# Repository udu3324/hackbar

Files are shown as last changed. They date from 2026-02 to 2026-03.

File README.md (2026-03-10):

# hackbar

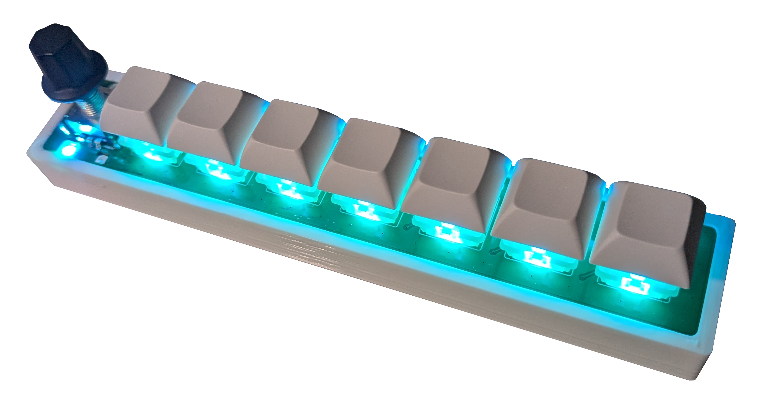
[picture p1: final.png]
hackbar photo


Hackbar is a macro keys pad in the shape of a bar designed to be placed on the long side of your keyboard. It features 7 switches, an encoder, and two neopixels per key and encoder. It is also inspired by the [Google g-board april fools video](https://www.youtube.com/watch?v=9G3DWHf1xX0). 

# firmware

KMK firmware is used to tell what the mcu sends to the host device when recieving switch inputs. 

# CAD

The cad can be found on [onshape](https://cad.onshape.com/documents/5cba3b888e11db533a85f54f/w/c697cc47e3473bff9588772d/e/0aef22490cba32d3fbb4fb29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). 

# Why I Made It

I wanted a macro keyboard that felt like the media control boards used in the a/v industry. They feature toggled leds that are vibrant and bright and look satisfying. I also would like to share this board with some of my friends as its very simple and easy to understand.

# How to Use 

The Seeed Xiao RP2040 makes flashing code very easy through circuitpython on the usb-c. 

# Photos

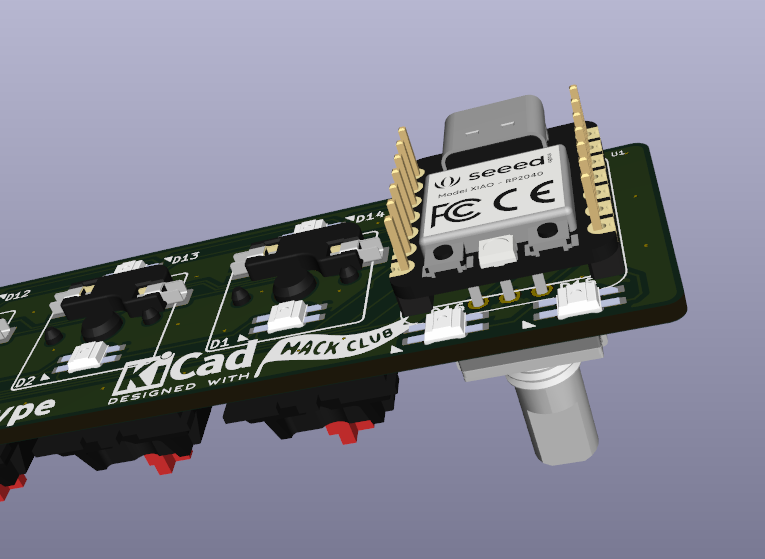
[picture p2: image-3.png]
render 2


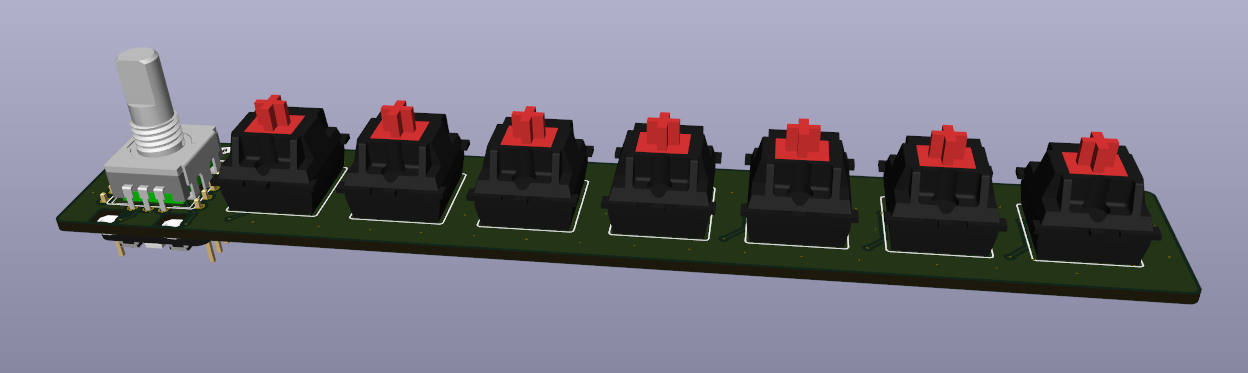
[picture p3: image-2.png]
render 1


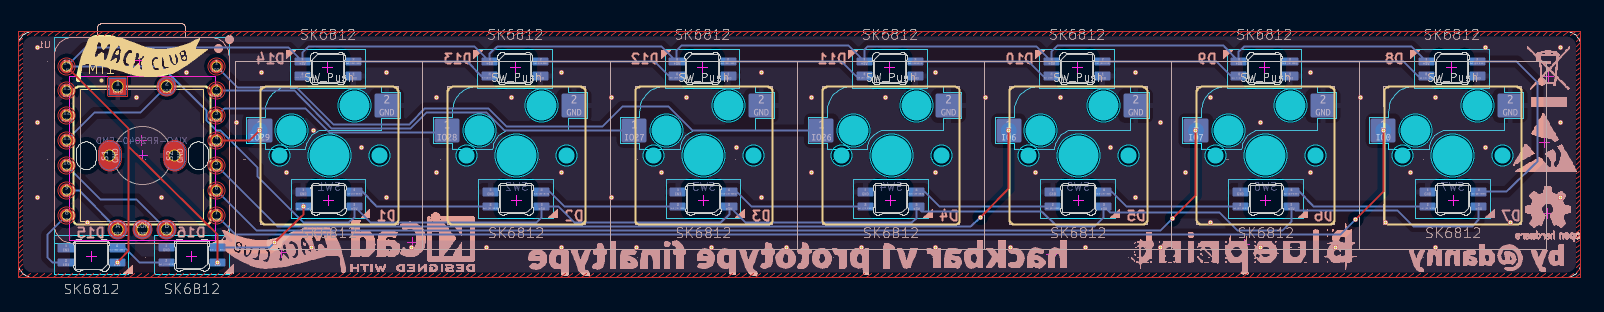
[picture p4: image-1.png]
pcb


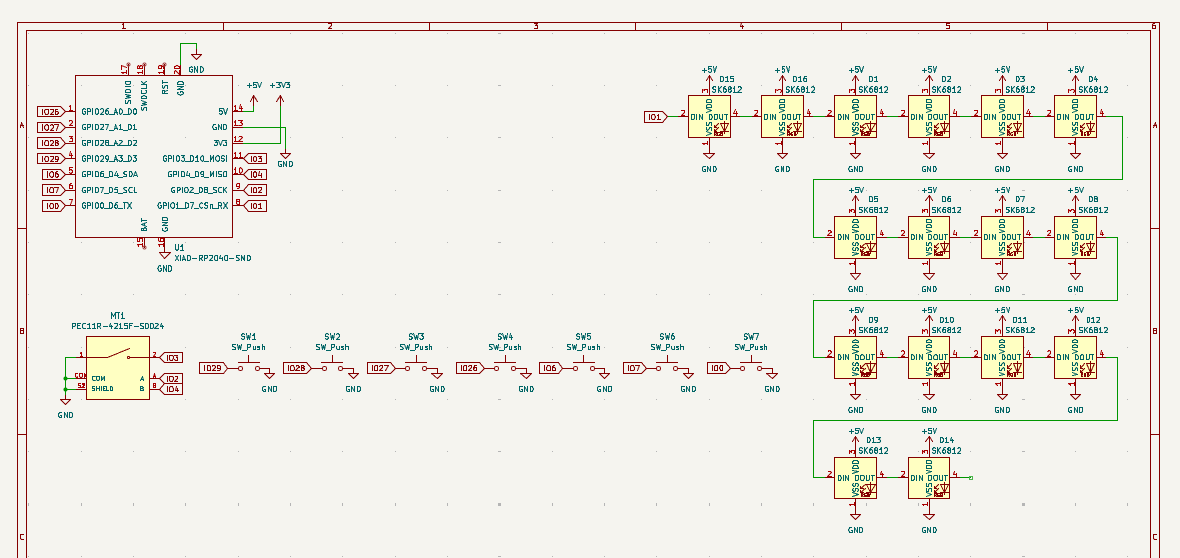
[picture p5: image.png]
schematics


# Bill of Materials

|Part |Quantity|On hand|Price |
|---|---|---|---|
|DSA Keycaps |7 |no | |
|Switches |7 |no | |
|Rotary Encoder Cap|1 |no | |
|Rotary Encoder |1 |no | |
|SK6812 MINI-E LEDs|16 |no | |
|PCB | |no |$9.55 |
|Seeed XIAO RP2040 |1 |no | |
|3d Printed Case |1 |yes | |
|Hot-swap Socket |7 |yes | |

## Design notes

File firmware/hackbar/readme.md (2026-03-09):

# hackbar

hackbar

*A short description of the keyboard/project*

* Keyboard Maintainer: [udu3324](https://github.com/udu3324)
* Hardware Supported: *The PCBs, controllers supported*
* Hardware Availability: *Links to where you can find this hardware*

Make example for this keyboard (after setting up your build environment):

    make hackbar:default

Flashing example for this keyboard:

    make hackbar:default:flash

See the [build environment setup](https://docs.qmk.fm/#/getting_started_build_tools) and the [make instructions](https://docs.qmk.fm/#/getting_started_make_guide) for more information. Brand new to QMK? Start with our [Complete Newbs Guide](https://docs.qmk.fm/#/newbs).

## Bootloader

Enter the bootloader in 3 ways:

* **Bootmagic reset**: Hold down the key at (0,0) in the matrix (usually the top left key or Escape) and plug in the keyboard
* **Physical reset button**: Briefly press the button on the back of the PCB - some may have pads you must short instead
* **Keycode in layout**: Press the key mapped to `QK_BOOT` if it is available

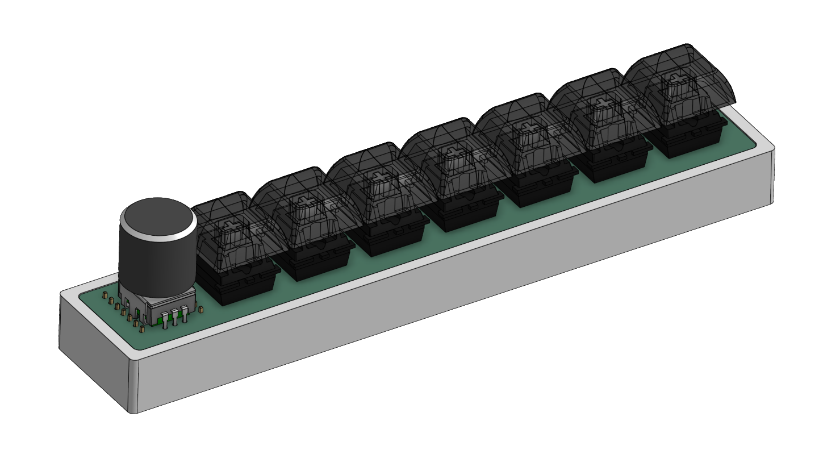
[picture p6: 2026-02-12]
img.png

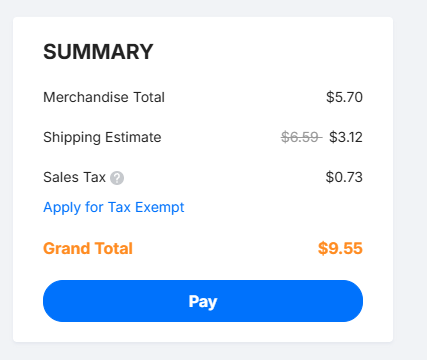
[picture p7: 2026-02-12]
cart.png

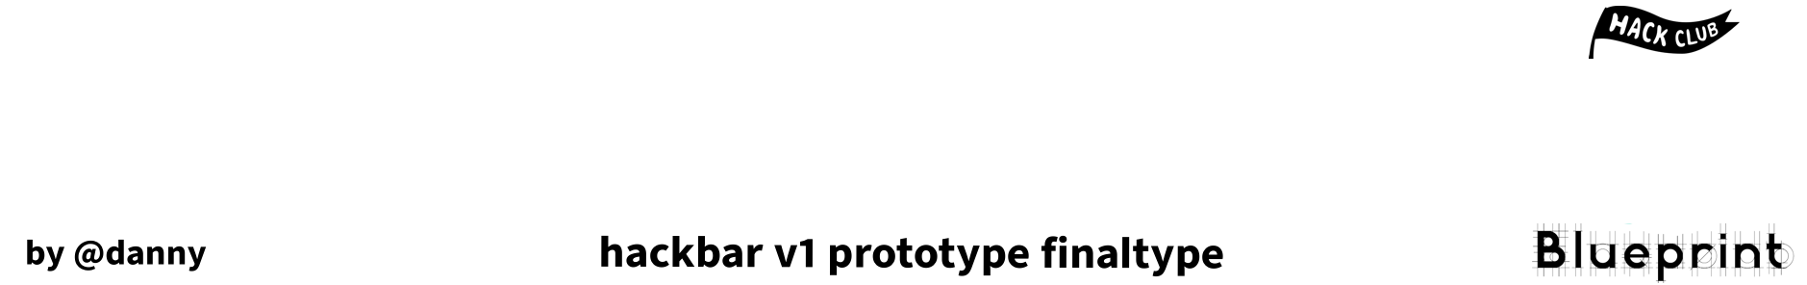
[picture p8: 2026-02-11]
pcb/hackbar-B_Silkscreen.png

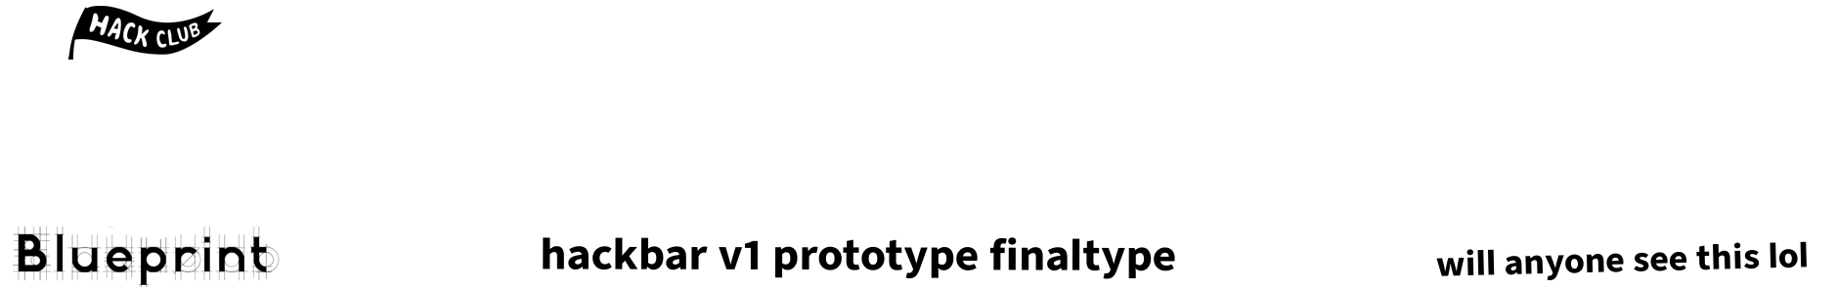
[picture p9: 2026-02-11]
pcb/hackbar-F_Silkscreen.png

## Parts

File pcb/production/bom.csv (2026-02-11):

Designator | Footprint | Quantity | Value | LCSC Part #
D1, D10, D11, D12, D13, D14, D2, D3, D4, D5, D6, D7, D8, D9 | SK6812MINI-E_fixed | 14 | SK6812
MT1 | PEC11R-4215F-S0024_XDCR_PEC11R-4215F-S0024 | 1 | PEC11R-4215F-S0024
SW1, SW2, SW3, SW4, SW5, SW6, SW7 | MX-Hotswap-1U | 7 | SW_Push
U1 | XIAO-RP2040-DIP | 1 | XIAO-RP2040-SMD

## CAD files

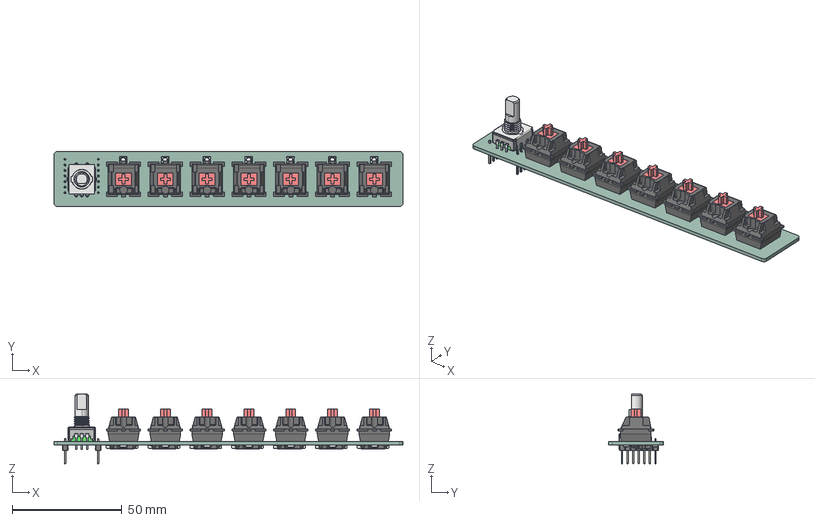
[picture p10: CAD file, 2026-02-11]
cad/hackbar pcb.step
159.0 x 25.0 x 31.7 mm
SK6812-E--3DModel-STEP-418109 x 14
PEC11R-4215F-S0024
MX-Hotswap-Socket x 7
PinHeader_1x07_P2.54mm_Vertical x 2
hackbar_PCB

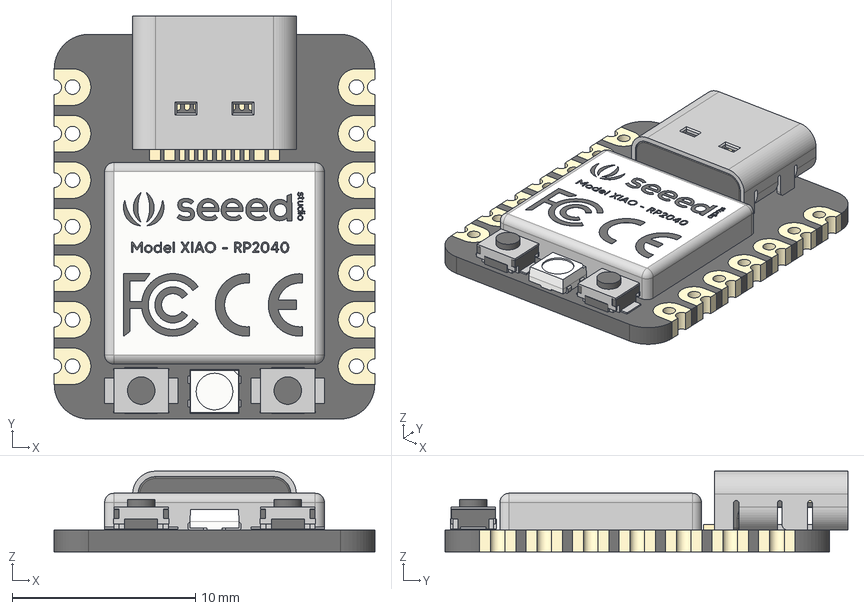
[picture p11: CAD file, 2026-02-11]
pcb/Seeed Studio XIAO RP2040 v26.step
17.5 x 22.0 x 4.40 mm
type-c v2
smd_button v3
DOUT
DIN
VSS
VDD
smd_button v3(Mirror)

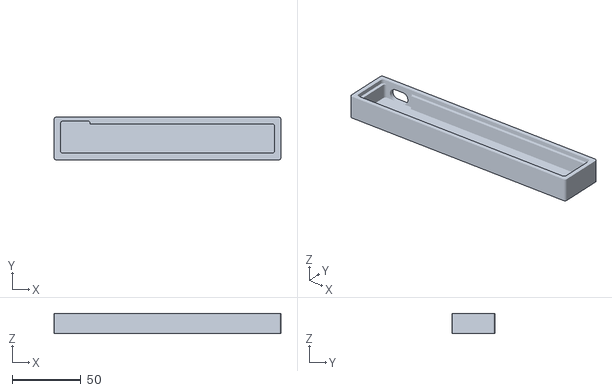
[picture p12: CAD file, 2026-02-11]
cad/hackbar case.stl
165.0 x 31.0 x 14.9

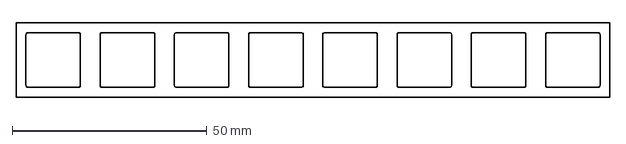
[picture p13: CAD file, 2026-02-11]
pcb/plate-2026-02-11T03_17_20.273Z.dxf
152.4 x 19.1 mm

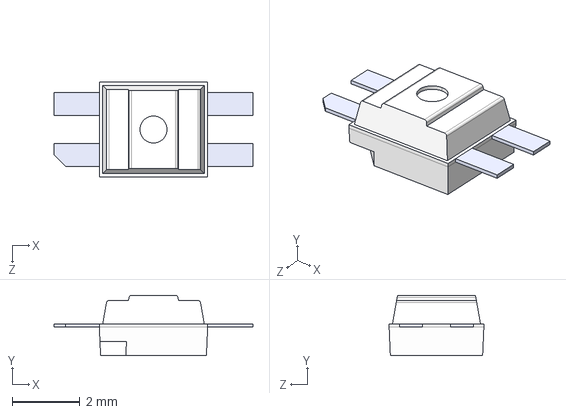
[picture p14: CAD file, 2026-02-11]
pcb/SK6812-E--3DModel-STEP-418109.STEP
5.88 x 1.78 x 2.80 mm

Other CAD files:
cad/hackbar case.x_t

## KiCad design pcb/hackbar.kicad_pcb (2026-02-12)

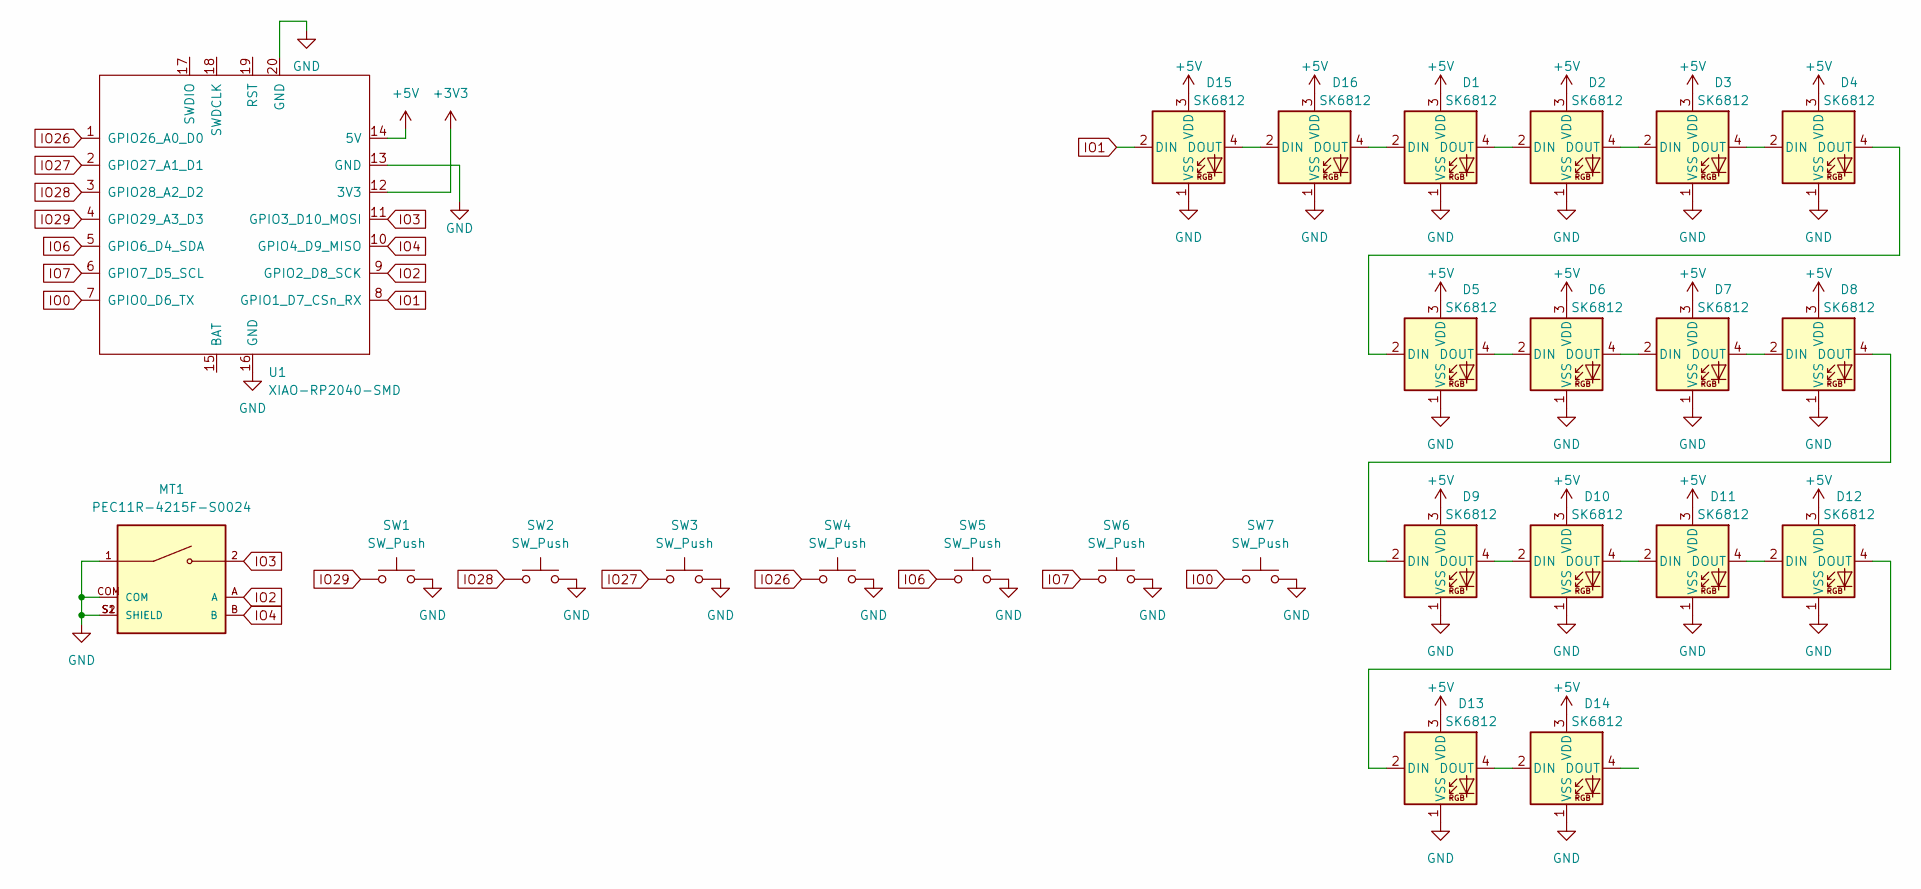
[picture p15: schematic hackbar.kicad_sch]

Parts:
D1, D2, D3, D4, D5, D6, D7, D8, D9, D10, D11, D12, D13, D14, D15, D16: SK6812; SK6812MINI-E_fixed
MT1: PEC11R-4215F-S0024; PEC11R-4215F-S0024_XDCR_PEC11R-4215F-S0024; PARTREV Rev. 09/19
SW1, SW2, SW3, SW4, SW5, SW6, SW7: SW_Push; MX-Hotswap-1U
U1: XIAO-RP2040-SMD; XIAO-RP2040-DIP

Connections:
+3V3: U1.12 (3V3)
+5V: D1.3 (VDD), D2.3 (VDD), D3.3 (VDD), D4.3 (VDD), D5.3 (VDD), D6.3 (VDD), D7.3 (VDD), D8.3 (VDD), D9.3 (VDD), D10.3 (VDD), D11.3 (VDD), D12.3 (VDD), D13.3 (VDD), D14.3 (VDD), D15.3 (VDD), D16.3 (VDD), U1.14 (5V)
GND: D1.1 (VSS), D2.1 (VSS), D3.1 (VSS), D4.1 (VSS), D5.1 (VSS), D6.1 (VSS), D7.1 (VSS), D8.1 (VSS), D9.1 (VSS), D10.1 (VSS), D11.1 (VSS), D12.1 (VSS), D13.1 (VSS), D14.1 (VSS), D15.1 (VSS), D16.1 (VSS), MT1.1, MT1.COM, MT1.S1 (SHIELD), MT1.S2 (SHIELD), SW1.2, SW2.2, SW3.2, SW4.2, SW5.2, SW6.2, SW7.2, U1.13 (GND), U1.16 (GND), U1.20 (GND)
IO0: SW7.1, U1.7 (GPIO0_D6_TX)
IO1: D15.2 (DIN), U1.8 (GPIO1_D7_CSn_RX)
IO2: MT1.A, U1.9 (GPIO2_D8_SCK)
IO3: MT1.2, U1.11 (GPIO3_D10_MOSI)
IO4: MT1.B, U1.10 (GPIO4_D9_MISO)
IO6: SW5.1, U1.5 (GPIO6_D4_SDA)
IO7: SW6.1, U1.6 (GPIO7_D5_SCL)
IO26: SW4.1, U1.1 (GPIO26_A0_D0)
IO27: SW3.1, U1.2 (GPIO27_A1_D1)
IO28: SW2.1, U1.3 (GPIO28_A2_D2)
IO29: SW1.1, U1.4 (GPIO29_A3_D3)
unnamed: D1.2 (DIN), D16.4 (DOUT)
unnamed: D1.4 (DOUT), D2.2 (DIN)
unnamed: D2.4 (DOUT), D3.2 (DIN)
unnamed: D3.4 (DOUT), D4.2 (DIN)
unnamed: D4.4 (DOUT), D5.2 (DIN)
unnamed: D5.4 (DOUT), D6.2 (DIN)
unnamed: D6.4 (DOUT), D7.2 (DIN)
unnamed: D7.4 (DOUT), D8.2 (DIN)
unnamed: D8.4 (DOUT), D9.2 (DIN)
unnamed: D9.4 (DOUT), D10.2 (DIN)
unnamed: D10.4 (DOUT), D11.2 (DIN)
unnamed: D11.4 (DOUT), D12.2 (DIN)
unnamed: D12.4 (DOUT), D13.2 (DIN)
unnamed: D13.4 (DOUT), D14.2 (DIN)
unnamed: D15.4 (DOUT), D16.2 (DIN)

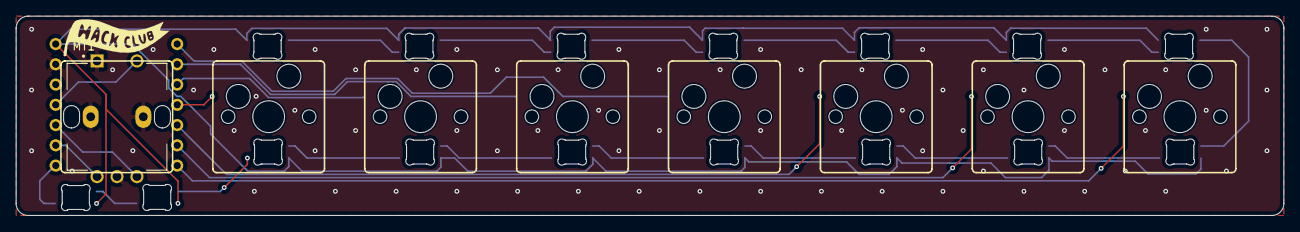
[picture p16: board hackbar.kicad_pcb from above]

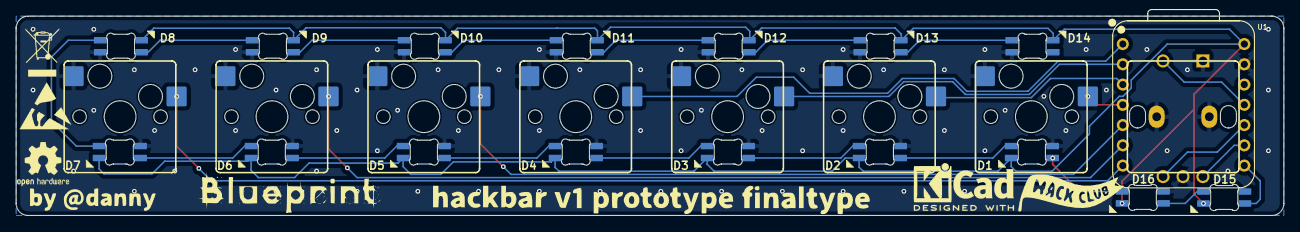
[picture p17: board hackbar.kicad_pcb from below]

Board: 2 copper layers, 159.0 x 25.0 mm, 25 parts (8 on the bottom side), 28 nets.

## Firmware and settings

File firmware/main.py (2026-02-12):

import board
from kmk.kmk_keyboard import KMKKeyboard
from kmk.keys import KC
from kmk.modules.encoder import EncoderHandler
from kmk.extensions.rgb import RGB
from kmk.modules.macros import Press, Release, Tap, Macros

# Initialize
keyboard = KMKKeyboard()

keyboard.diode_orientation = None

keyboard.modules.append(Macros())

# direct pin to switches, no matrix
keyboard.direct_pins = [
    board.D3,
    board.D2,
    board.D1,
    board.D0,
    board.D4,
    board.D5,
    board.D6
]

# Knob
encoder_handler = EncoderHandler()
encoder_handler.pins = (
    (board.D8, board.D9, board.D10, False),
)
# Knob click toggles between layers
encoder_handler.map = [
    ((KC.MEDIA_VOLUME_UP, KC.MEDIA_VOLUME_DOWN, KC.TG(1)),),
    ((KC.MEDIA_VOLUME_UP, KC.MEDIA_VOLUME_DOWN, KC.TG(1)),),
]

keyboard.modules.append(encoder_handler)

# LEDs
rgb = RGB(
    pixel_pin=board.D7,
    num_pixels=16,
    rgb_order='GRB',
    animation_mode=RGB.RAINBOW
)
keyboard.extensions.append(rgb)

# ex. of macro: KC.MACRO(Press(KC.LCTRL), Tap(KC.C), Release(KC.LCTRL))

# Keymap
keyboard.keymap = [
    # Layer 0:
    [
        KC.Q, 
        KC.W, 
        KC.E, 
        KC.R, 
        KC.T, 
        KC.Y, 
        KC.U
    ],
    
    # Layer 1:
    [
        KC.PSCREEN, # screenshot
        KC.MACRO(Press(KC.LALT), Tap(KC.F9), Release(KC.LALT)), # record toggle
        KC.MACRO(Press(KC.LALT), Press(KC.LSHIFT), Tap(KC.F10), Release(KC.LSHIFT), Release(KC.LALT)), # instant replay
        KC.Q, 
        KC.W, 
        KC.E, 
        KC.LWIN(KC.L) # lock screen
    ],
]

if __name__ == '__main__':
    keyboard.go()

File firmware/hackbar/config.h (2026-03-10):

// Copyright 2023 QMK
// SPDX-License-Identifier: GPL-2.0-or-later

#pragma once

#define RGBLIGHT_LIMIT_VAL 60
#define RGBLIGHT_SLEEP
#define RGBLIGHT_LAYERS

#define ENCODER_RESOLUTION 4
#define ENCODER_DEBOUNCE 10

// neopixel led allocation - 
// encoder: 1, 2
// key 1:   3, 16
// key 2:   4, 15
// key 3:   5, 14
// key 4:   6, 13
// key 5:   7, 12
// key 6:   8, 11
// key 7:   9, 10
#define RGBLIGHT_LED_MAP {0, 1, 2, 15, 3, 14, 4, 13, 5, 12, 6, 11, 7, 10, 8, 9}

#define RGBLIGHT_EFFECT_BREATHING
#define RGBLIGHT_EFFECT_RAINBOW_MOOD
#define RGBLIGHT_EFFECT_RAINBOW_SWIRL
#define RGBLIGHT_EFFECT_SNAKE
#define RGBLIGHT_EFFECT_KNIGHT

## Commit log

2026-02-11 pcb layout + final touches + cad
    [SK6812-E--3DModel-STEP-418109.STEP, Seeed Studio XIAO RP2040 v26.step, bom.csv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]
2026-02-12 add cad, images, readme, bom
    [BOM.csv, bom.csv, designators.csv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]
